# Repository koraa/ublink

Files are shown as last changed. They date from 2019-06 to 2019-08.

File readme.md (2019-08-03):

# µBlink

PWM Control for high power leds

## Features

* ESP32 CPU
* Access console via USB
* External antenna support
* High Voltage Relais to turn 

## Copying

Copyright 2018-2019 by Karolin Varner.

Hardware is licensed under CERN Open Hardware Licence v1.2.
Software is licensed under MIT license.

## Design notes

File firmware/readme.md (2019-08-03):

# µBlink firmware

Edit any configuration you need to edit in build_config.sh (or leave it as it is),

To compile µBlink, just use the provided build script. This will also install esp-idf and
the required toolchains automatically.

```sh
$ ./build.sh
```

In order to flash your µBlink, press the 'flash' button on your board and
use the following command:

```sh
$ ./build.sh flash [SERIAL_DEVICE]
```

Check out the build.sh command for further options:

```sh
$ ./build.sh help
```

## Makefile

For your convenience, a makefile is provided:

```sh
$ UBLINK_DEVICE=$SERIAL_DEVICE make build flash
```

## Configuration

Edit build_config.sh or provide the appropriate environment variables manually.

E.g. the following command could be used to install the toolchain at a custom location (provided the build_config.sh is untouched).

```sh
IDF_PATH="$HOME/esp-idf" IDF_TOOLS_PATH="$HOME/esp-idf/toolchain" ./build.sh setup_toolchain
```

## Todo

* Set up LED PWM
* WIFI
* CLI

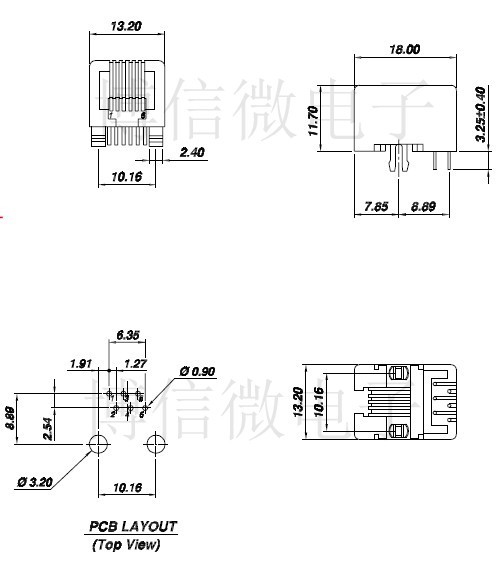
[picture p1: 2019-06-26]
datasheets/rj12.jpg

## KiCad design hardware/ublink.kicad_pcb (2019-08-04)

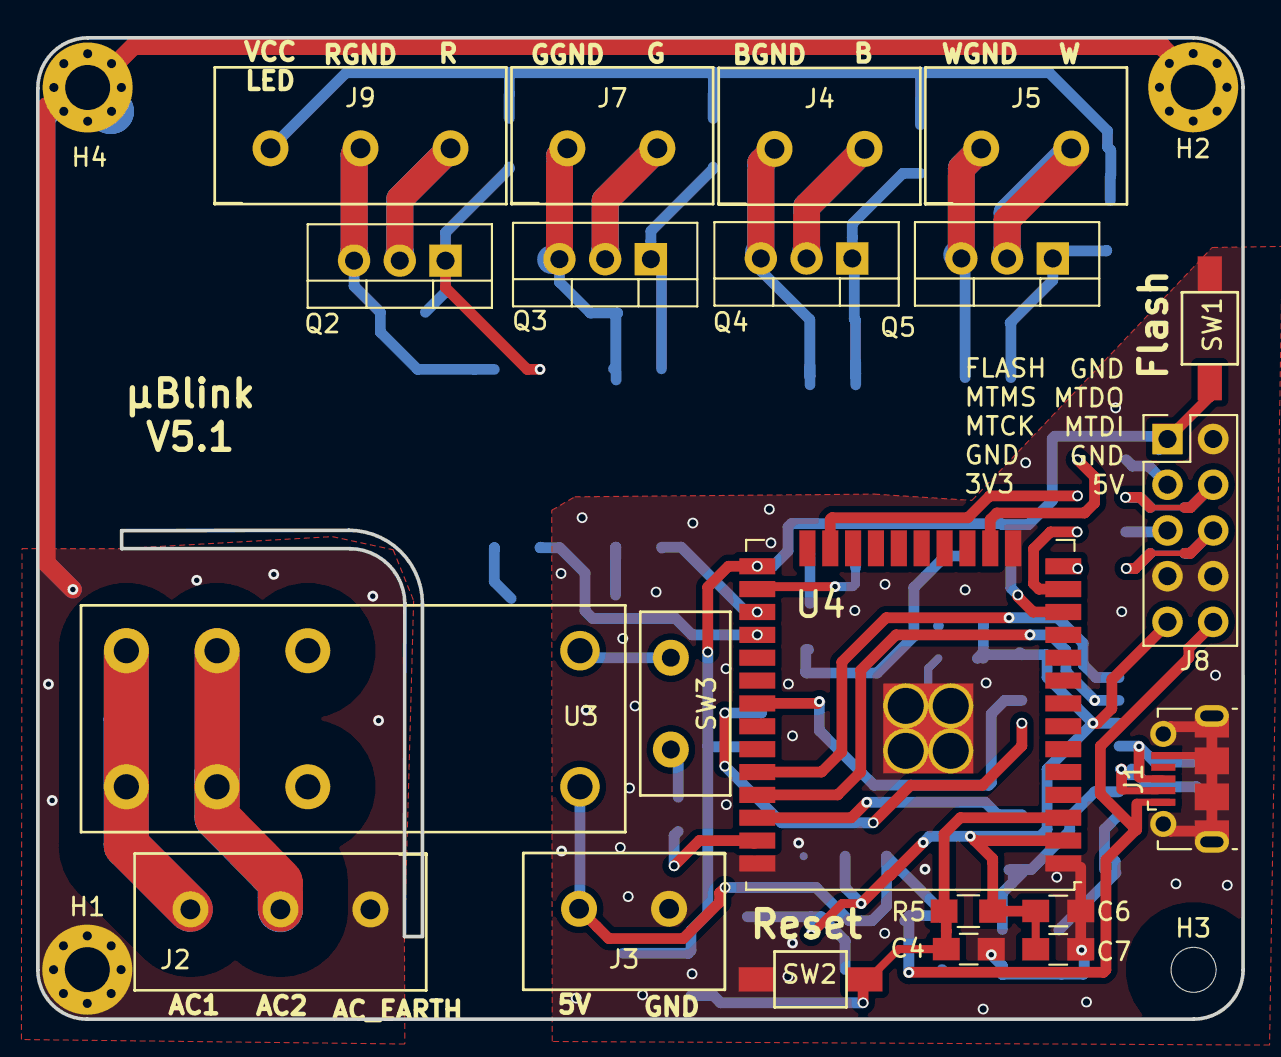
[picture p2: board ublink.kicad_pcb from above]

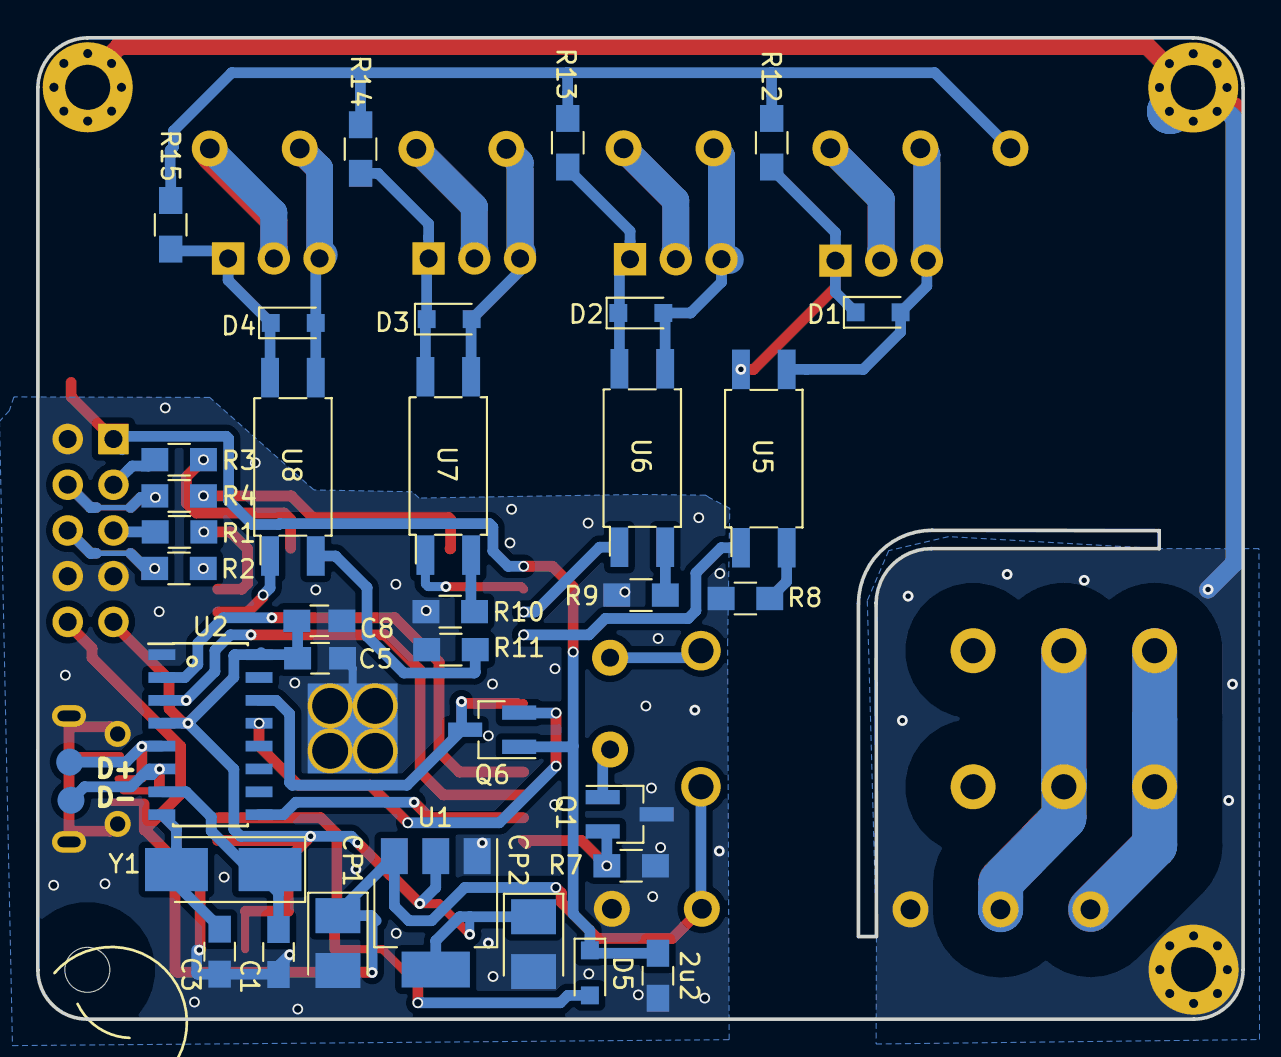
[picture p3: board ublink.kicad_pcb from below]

Board: 2 copper layers, 67.0 x 54.5 mm, 61 parts (36 on the bottom side), 49 nets.

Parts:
2u2: CP2; C_0805_HandSoldering
10u1: C8; C_0805_HandSoldering
10u2: C7; C_0805_HandSoldering
100u1: CP1; CP_Tantalum_Case-B_EIA-3528-21_Reflow
100u2: CP2; CP_Tantalum_Case-B_EIA-3528-21_Reflow
C1, C3: 22p; C_0805_HandSoldering
C4: 0.1u; C_0805_HandSoldering
C5, C6: 100n; C_0805_HandSoldering
D1, D2, D3, D4: 18V; D_SOD-323_HandSoldering
D5: D; D_SOD-323_HandSoldering
H1, H2, H4: MountingHole; MountingHole_2.5mm_Pad_Via
H3: MountingHole; MountingHole_2.5mm
J1: USB_B_Micro; USB_Micro-B_Molex-105017-0001
J2: AC1; KF301-5.0-3P
J3: 5V Trafo; KF301-5.0-2P
J4, J5, J7: Screw_Terminal_01x02; KF301-5.0-2P
J8: Pin Header; Pin_Header_Straight_2x05_Pitch2.54mm
J9: Screw_Terminal_01x02; KF301-5.0-3P
Q1, Q6: STN3NF06L; SOT-23_Handsoldering
Q2, Q3, Q4, Q5: RU6099; TO-220-3_Vertical
R1, R2, R3, R4, R8, R9, R10, R11: 100; R_0805_HandSoldering
R5, R7: 10k; R_0805_HandSoldering
R12, R13, R14, R15: 20k; R_0805_HandSoldering
SW1, SW2: SW_Push; pushbutton_2
SW3: JUC-31F
TP1, TP2: TestPoint; Measurement_Point_Round-SMD-Pad_Small
U1: 3.3V3 Regul; lm-1117
U2: CH340G; CH403G
U3: HF115F_005-1ZS3
U4: ESP32-WROOM-32U
U5, U6, U7, U8: EL817S
Y1: 12Mhz; Crystal_SMD_5032-2pin_5.0x3.2mm_HandSoldering

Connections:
3V3: 10u1.1, 10u2.1, 100u2.1, C5.1, C6.1, J8.9, R5.1, U1.2, U2.4, U2.16, U4.2
5V: 100u1.1, J1.1, J3.2, J8.10, U1.3, U3.1
/B_GATE: D3.1, Q4.1, R14.2, U7.4
/B_GND: D3.2, J4.1, Q4.3, U7.3
/B_LED: J4.2, Q4.2
/G_GATE: D2.1, Q3.1, R13.2, U6.4
/G_GND: D2.2, J7.1, Q3.3, U6.3
/G_LED: J7.2, Q3.2
/LED_VCC: J9.1, R12.1, R13.1, R14.1, R15.1
/R_GATE: D1.1, Q2.1, R12.2, U5.4
/R_GND: D1.2, J9.2, Q2.3, U5.3
/R_LED: J9.3, Q2.2
/USB_D+: J1.3, TP2.1, U2.5
/USB_D-: J1.2, TP1.1, U2.6
/W_GATE: D4.1, Q5.1, R15.2, U8.4
/W_GND: D4.2, J5.1, Q5.3, U8.3
/W_LED: J5.2, Q5.2
/XI: C1.1, U2.7, Y1.1
AC1: J2.2, U3.5, U3.6
AC2: J2.3, U3.7, U3.8
AC_SAFE: H1.1, H2.1, H4.1, J2.1
B_CTRL: U4.26, U7.1
CTS: U2.9, U4.36
DTR: Q6.2, U2.13
EN: C4.1, D5.2, R5.2, SW2.1, U4.3
FLASH: 2u2.1, D5.1, J8.1, Q6.1, SW1.2, U4.25
GND: 2u2.2, 10u1.2, 10u2.2, 100u1.2, 100u2.2, C1.2, C3.2, C4.2, C5.2, C6.2, J1.5, J1.6, J3.1, J8.2, J8.7, J8.8, Q1.3, R7.2, R8.1, R9.1, R10.1, R11.1, SW1.1, SW2.2, U1.1, U2.1, U4.1, U4.15, U4.38, U4.39
G_CTRL: U4.27, U6.1
MTCK: R3.1, U4.16
MTDI: R2.2, U4.14
MTDO: R4.2, U4.23
MTMS: R1.1, U4.13
unnamed: C3.1, U2.8, Y1.2
unnamed: J8.3, R3.2
unnamed: J8.4, R4.1
unnamed: J8.5, R1.2
unnamed: J8.6, R2.1
unnamed: Q1.1, SW3.1
unnamed: R8.2, U5.2
unnamed: R9.2, U6.2
unnamed: R10.2, U7.2
unnamed: R11.2, U8.2
unnamed: SW3.2, U3.2
RELAIS_CTRL: Q1.2, R7.1, U4.37
RTS: Q6.3, U2.14, U4.31
RX: U2.3, U4.35
R_CTRL: U4.28, U5.1
TX: U2.2, U4.34
W_CTRL: U4.12, U8.1

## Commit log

2019-07-25 Fix layout errors
    [ublink.kicad_pcb, ublink.sch]
2019-07-31 Initial firmware
    [ublink.kicad_pcb]
2019-08-02 Animate a single led
2019-08-03 v5 PCB: Flash button nau auto resets
    Flash button exposed via pin headers; no more UART
    via pin headers.
    Lights are on pins that can actually be used.
    [ublink.kicad_pcb, ublink.sch]
2019-08-04 Hardware v5.1: Reset when DTR is high
    This allows esptool.py to reset the µC and boot into
    uart downloader mode without the user having to press
    a button.
    [ublink.kicad_pcb, ublink.sch]
